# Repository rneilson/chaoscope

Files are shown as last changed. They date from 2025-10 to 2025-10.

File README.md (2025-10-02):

# Chaoscope

Infrared camera, Raspberry Pi, Lidar, in a convenient ~~vampire hunting~~ pistol grip form factor.

It's mostly ten-year-old kit -- a Pi 2, a 5 MP IR cut cam -- but hey, this
is more productive than the scrap heap...

### Major Components

- [Raspberry Pi 2 B](https://www.raspberrypi.com/products/raspberry-pi-2-model-b/)
- [Waveshare IR CUT 5MP camera](https://www.waveshare.com/wiki/RPi_IR-CUT_Camera)
- [M5Stack dual button unit](https://docs.m5stack.com/en/unit/dual_button)
- INA219 current/voltage monitor
- TP5100 battery charger
- 5V switching buck/boost voltage regulator
- 1 x 18650 lithium-ion battery

### Final form

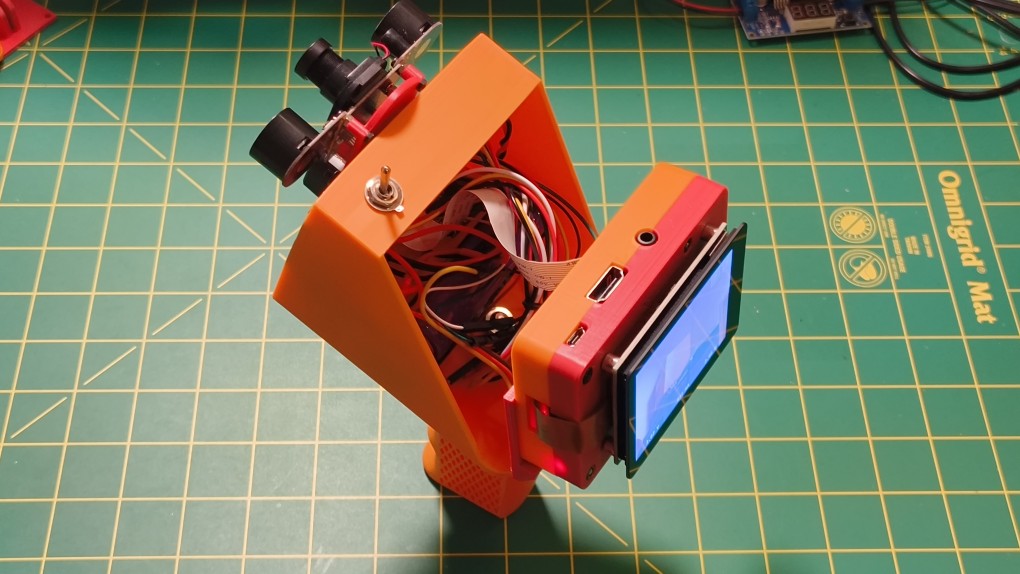
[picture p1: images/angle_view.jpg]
Angle view


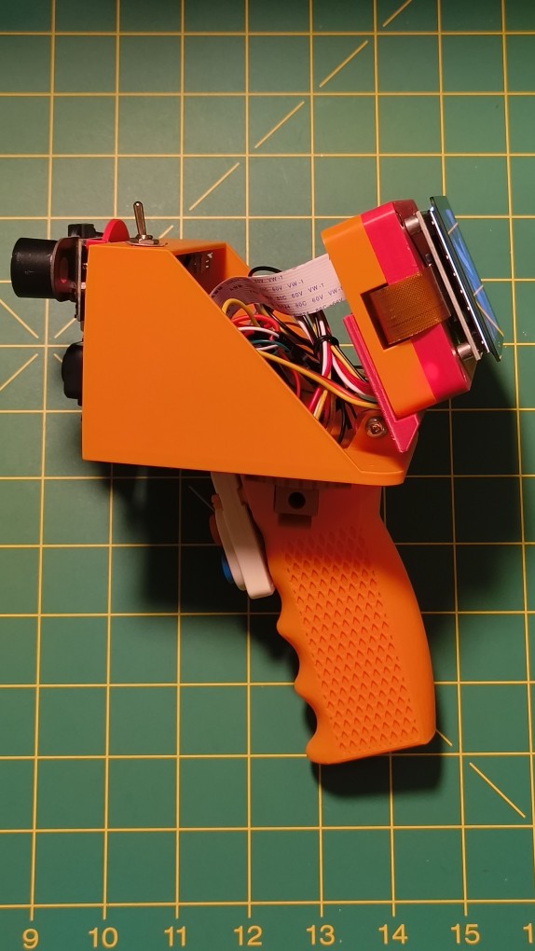
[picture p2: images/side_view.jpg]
Side view


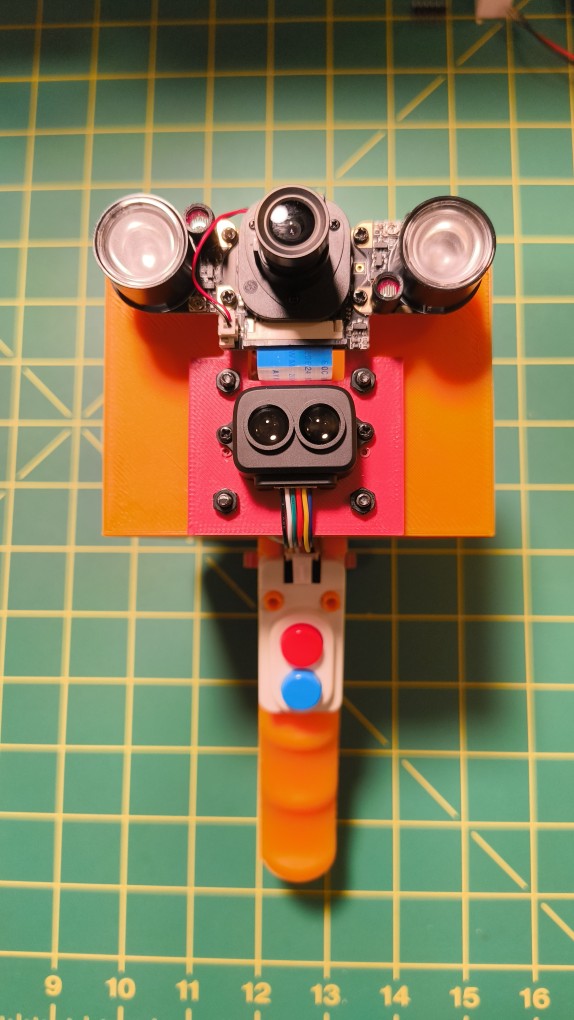
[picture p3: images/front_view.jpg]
Front view


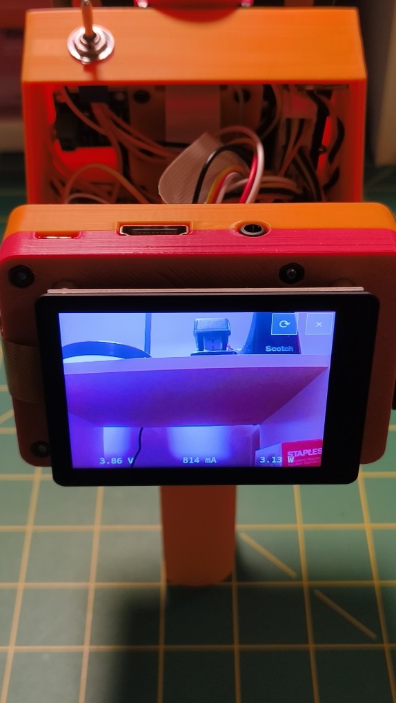
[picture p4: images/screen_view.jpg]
Screen view


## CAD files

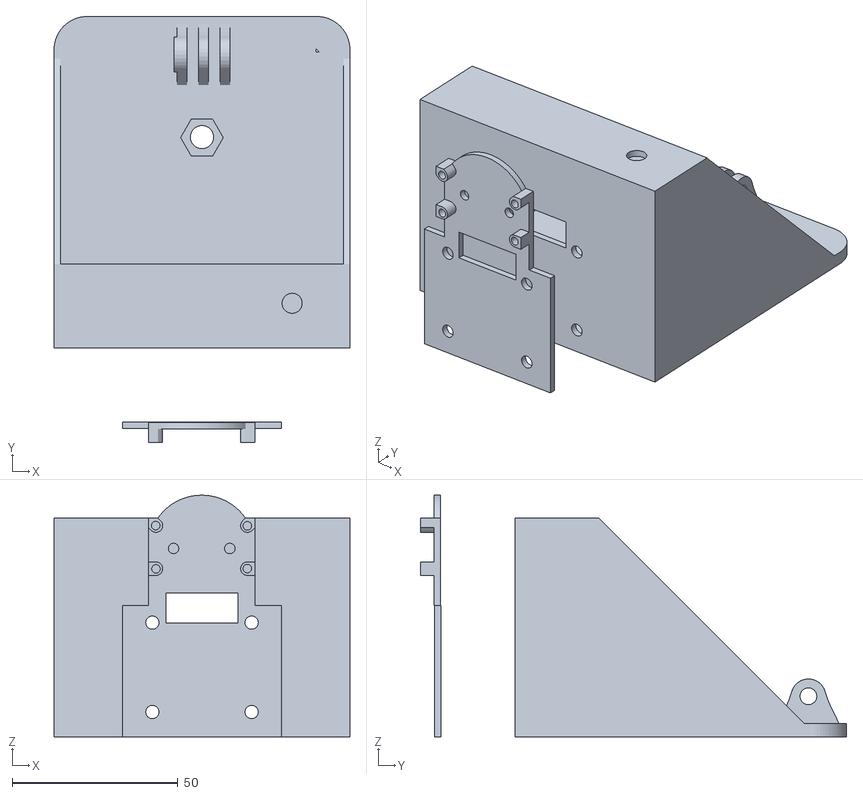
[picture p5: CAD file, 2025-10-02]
files/Camera bracket tall.stl
89.4 x 128.7 x 73.0

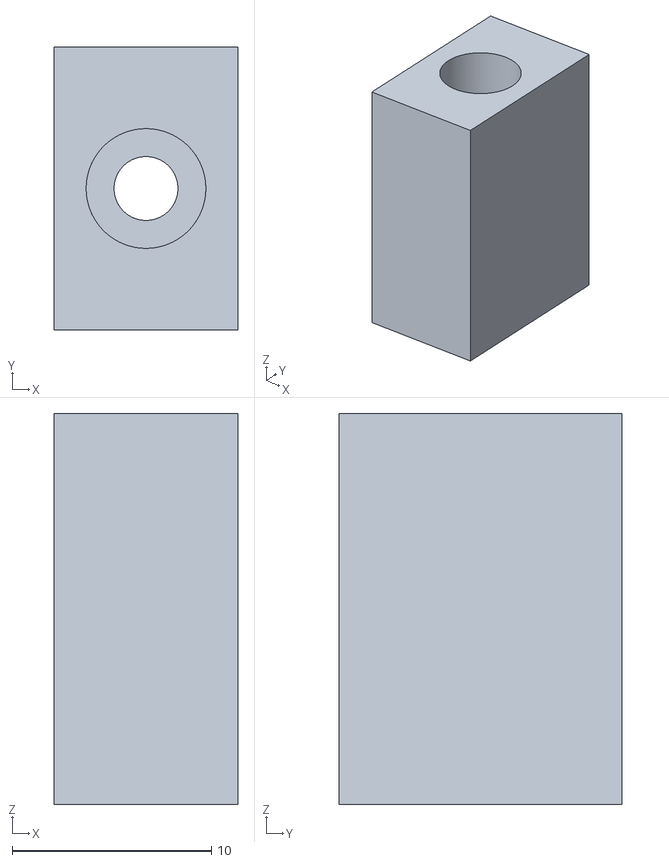
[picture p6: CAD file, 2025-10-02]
files/grip-insert.stl
9.20 x 14.2 x 19.6

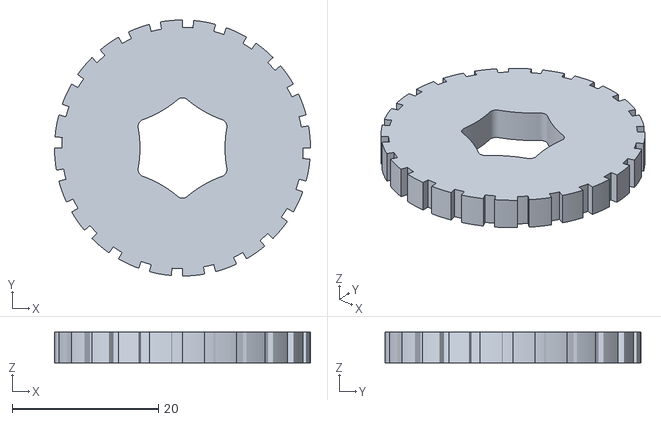
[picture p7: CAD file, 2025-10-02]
files/grip-thumbwheel.stl
35.0 x 35.0 x 4.20

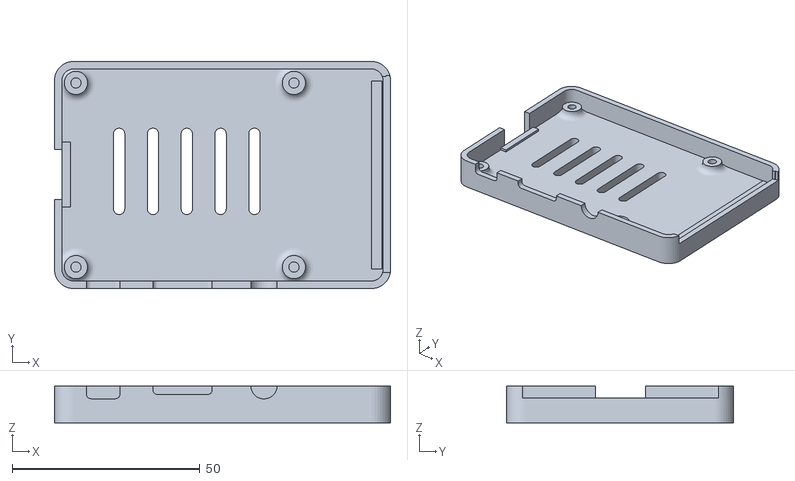
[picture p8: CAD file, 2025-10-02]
files/Pi3_Bottom_Vents.stl
89.4 x 60.4 x 9.75

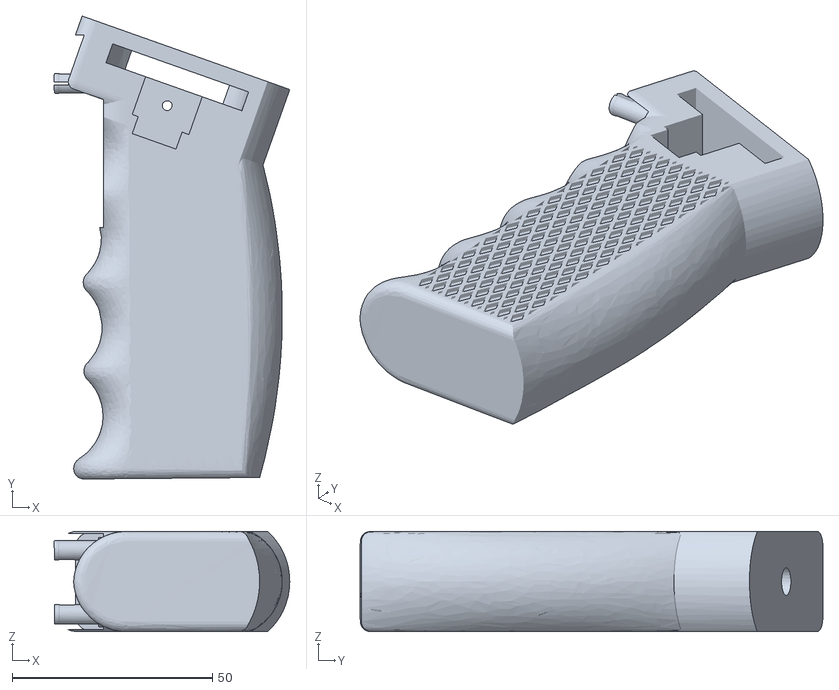
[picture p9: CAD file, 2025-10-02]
files/Pistol grip with dual button slot v2.stl
58.8 x 115.6 x 25.0

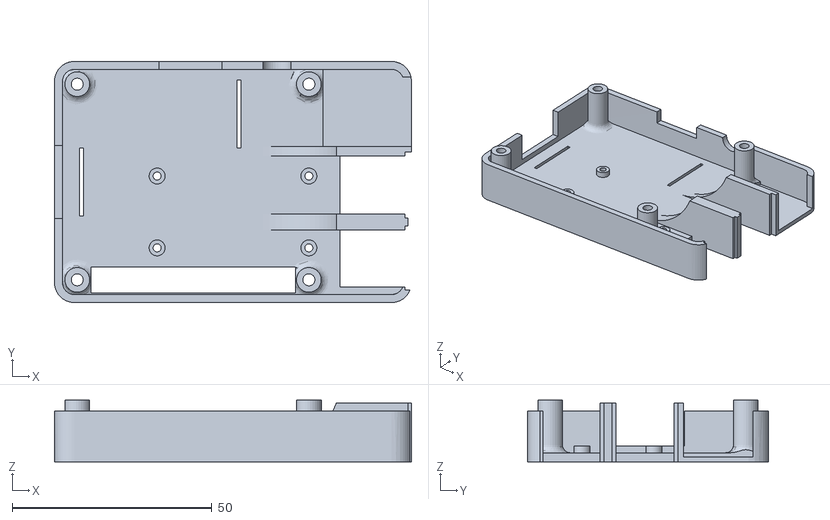
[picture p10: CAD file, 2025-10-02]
files/Pi3_Top_GPIO_modified_2.stl
89.4 x 60.4 x 15.5

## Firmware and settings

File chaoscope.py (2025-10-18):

import json
import os
import sys
from collections import deque
from dataclasses import dataclass
from datetime import datetime
from enum import StrEnum
from math import cos, radians, sin
from pathlib import Path
from time import sleep
from typing import TYPE_CHECKING, Any, Callable

import numpy as np
from PyQt5.QtCore import (
    Qt,
    QPoint,
    QObject,
    QRect,
    QThread,
    QTimer,
    pyqtSignal,
    pyqtSlot,
)
from PyQt5.QtGui import QFont, QPainter, QPaintEvent, QPen
from PyQt5.QtWidgets import (
    QPushButton,
    QHBoxLayout,
    QVBoxLayout,
    QApplication,
    QWidget,
    QLabel,
)
from ahrs import DEG2RAD, RAD2DEG
from ahrs.common.quaternion import Quaternion
from ahrs.filters.tilt import Tilt
from ahrs.filters.madgwick import Madgwick
from gpiozero import Button, DigitalInputDevice
from numpy import array, ndarray
from smbus2 import SMBus

from chaoscope_lib.inertial import IMU, ONE_G
from chaoscope_lib.magnometer import Magnometer, MagnometerCalibration

if TYPE_CHECKING:
    from picamera2 import CompletedRequest, Picamera2  # type: ignore
    from picamera2.encoders import H264Encoder  # type: ignore
    from picamera2.outputs import PyavOutput  # type: ignore
    from picamera2.previews.qt import QGlPicamera2  # type: ignore

TRANSLUCENT_STYLESHEET = (
    "color: white; background-color: rgba(255, 255, 255, 63); border: 1px solid white; "
)
TRANSPARENT_STYLESHEET = (
    "color: white; background-color: rgba(255, 255, 255, 0); border: none; "
)
FONT_SM = QFont("Deja Vu Sans Mono", 12)
FONT_MD = QFont("Deja Vu Sans Mono", 18)
FONT_LG = QFont("Deja Vu Sans Mono", 24)

LIDAR_I2C_ADDRESS = 0x10
LIDAR_REG_DIST = 0x00
LIDAR_REG_ENABLE = 0x25
LIDAR_REG_FREQ = 0x26
LIDAR_REG_MODE = 0x23
LIDAR_REG_SAVE = 0x20
LIDAR_REG_REBOOT = 0x21
LIDAR_REG_TRIGGER = 0x24

ENABLE_RETICLE = True

BASE_DIR = Path(__file__).parent
PHOTO_DIR = BASE_DIR / "photos"
CAL_FILE = BASE_DIR / "calibration.json"

if run_dir := os.environ.get("XDG_RUNTIME_DIR"):
    SHUTDOWN_FILE = Path(run_dir) / "chaoscope-shutdown"
else:
    SHUTDOWN_FILE = None

CURRENT_TZ = datetime.now().astimezone().tzinfo


class OverlayWindow(QWidget):
    exit_code: int
    finish = pyqtSignal()

    def __init__(
        self,
        parent: QWidget | None = None,
        flags: Qt.WindowFlags | Qt.WindowType = Qt.WindowFlags(),
    ) -> None:
        super().__init__(parent, flags)
        self.setWindowFlag(Qt.WindowType.FramelessWindowHint)
        self.setWindowTitle("Chaoscope controls")
        self.setAttribute(Qt.WidgetAttribute.WA_TranslucentBackground, on=True)
        self.setCursor(Qt.CursorShape.BlankCursor)
        self.setFont(FONT_MD)
        self.exit_code = 0

    def bring_to_front(self):
        self.show()
        self.raise_()
        self.activateWindow()

    def on_close(self):
        # Set special exit code to indicate shutdown after exit
        self.exit_code = 2
        self.finish.emit()

    def on_restart(self):
        # Set successful exit code
        self.exit_code = 0
        self.finish.emit()


class Clock(QWidget):
    def __init__(
        self,
        parent: QWidget | None = None,
        flags: Qt.WindowFlags | Qt.WindowType = Qt.WindowFlags(),
    ):
        super().__init__(parent=parent, flags=flags)
        self._layout = QVBoxLayout(self)
        self._clock = QLabel()
        self._timer = QTimer(self)
        self._timer.setInterval(100)
        self._timer.timeout.connect(self.update_ui)
        self._timer.start()
        self.init_ui()

    def init_ui(self):
        self._clock.setStyleSheet(TRANSPARENT_STYLESHEET)
        self._clock.setFont(FONT_MD)
        self._clock.setAlignment(Qt.AlignmentFlag.AlignCenter)
        self._layout.addWidget(self._clock)
        self.update_ui()

    @pyqtSlot()
    def update_ui(self):
        now = datetime.now(tz=CURRENT_TZ)
        self._clock.setText(now.strftime("%Y-%m-%d %I:%M:%S %p"))
        self._clock.adjustSize()
        self.adjustSize()


@dataclass
class PowerState:
    voltage: float | None
    current: float | None
    power: float | None


class PowerReader(QObject):
    INTERVAL_MS = 1000

    _hwmon_dir: Path | None
    _timer: QTimer | None
    output = pyqtSignal(PowerState)
    finished = pyqtSignal()

    def __init__(self, parent: QObject | None = None):
        super().__init__(parent=parent)
        self._hwmon_dir = self._find_hwmon_dir()
        self._timer = None

    def _find_hwmon_dir(self) -> Path | None:
        for subdir in Path("/sys/class/hwmon").glob("hwmon*"):
            name_file = subdir / "name"
            if name_file.exists() and name_file.read_text().strip() == "ina219":
                return subdir
        return None

    def start(self):
        self._timer = QTimer(self)
        self._timer.timeout.connect(self.check_power_state)
        self._timer.start(self.INTERVAL_MS)

    def stop(self):
        self._timer.stop()
        self._timer = None
        self.finished.emit()

    def check_power_state(self):
        voltage = self.get_voltage()
        current = self.get_current()
        power = self.get_power()
        self.output.emit(PowerState(voltage=voltage, current=current, power=power))

    def get_voltage(self) -> float | None:
        """
        Gets battery voltage in V from hwmon sysfs interface
        """
        voltage_file0 = self._hwmon_dir / "in0_input"
        voltage_file1 = self._hwmon_dir / "in1_input"
        try:
            voltage_str0 = voltage_file0.read_text()
            voltage_str1 = voltage_file1.read_text()
        except FileNotFoundError:
            return None

        voltage = (float(voltage_str0) + float(voltage_str1)) / 1_000

        return voltage

    def get_current(self) -> int | None:
        """
        Gets battery current in mA from hwmon sysfs interface
        """
        current_file = self._hwmon_dir / "curr1_input"
        try:
            current_str = current_file.read_text()
        except FileNotFoundError:
            return None

        current = int(current_str)

        return current

    def get_power(self) -> float | None:
        """
        Gets battery power in W from hwmon sysfs interface
        """
        power_file = self._hwmon_dir / "power1_input"
        try:
            power_str = power_file.read_text()
        except FileNotFoundError:
            return None

        power = float(power_str) / 1_000_000

        return power


class PowerLabelKind(StrEnum):
    VOLTAGE = "voltage"
    CURRENT = "current"
    POWER = "power"


class PowerLabel(QLabel):
    label_kind: PowerLabelKind
    power_state: PowerState

    def __init__(
        self,
        kind: PowerLabelKind,
        parent: QWidget | None = None,
        flags: Qt.WindowFlags | Qt.WindowType = Qt.WindowFlags(),
    ):
        super().__init__(parent=parent, flags=flags)
        self.label_kind = kind
        self.power_state = PowerState(None, None, None)
        self.init_ui()

    def init_ui(self):
        self.setStyleSheet(TRANSPARENT_STYLESHEET)
        self.setFont(FONT_MD)
        self.setAlignment(Qt.AlignmentFlag.AlignCenter)
        self.update_ui()

    def update_ui(self):
        match self.label_kind:
            case PowerLabelKind.VOLTAGE:
                v = self.power_state.voltage or 0.0
                self.setText(f"{v:.2f} V")
            case PowerLabelKind.CURRENT:
                i = int(self.power_state.current or 0.0)
                self.setText(f"{i:4} mA")
            case PowerLabelKind.POWER:
                p = self.power_state.power or 0.0
                self.setText(f"{p:.2f} W")

    @pyqtSlot(PowerState)
    def on_power_reading(self, power_state: PowerState):
        self.power_state = power_state
        self.update_ui()


class PowerMonitor(QWidget):
    power_reading = pyqtSignal(PowerState)

    def __init__(
        self,
        parent: QWidget | None = None,
        flags: Qt.WindowFlags | Qt.WindowType = Qt.WindowFlags(),
    ) -> None:
        super().__init__(parent, flags)

        self.voltage_label = PowerLabel(PowerLabelKind.VOLTAGE)
        self.current_label = PowerLabel(PowerLabelKind.CURRENT)
        self.power_label = PowerLabel(PowerLabelKind.POWER)

        self.power_monitor_layout = QHBoxLayout(self)
        self.power_monitor_layout.addWidget(self.voltage_label)
        self.power_monitor_layout.addWidget(self.current_label)
        self.power_monitor_layout.addWidget(self.power_label)

        self.power_reading.connect(self.voltage_label.on_power_reading)
        self.power_reading.connect(self.current_label.on_power_reading)
        self.power_reading.connect(self.power_label.on_power_reading)


@dataclass
class HeadingState:
    roll: float
    pitch: float
    yaw: float

    def apply_declination(self, dec: float) -> None:
        """
        Apply magnetic declination to observed yaw value.
        """
        self.yaw += dec
        if self.yaw > 180.0:
            self.yaw -= 360.0
        elif self.yaw < -180.0:
            self.yaw += 360.0


class HeadingReader(QObject):
    READING_INTERVAL_MS = 40  # 25 Hz for now
    FINAL_ROTATION = Quaternion(rpy=array([0.0, 0.0, 90.0]) * DEG2RAD)
    MAG_DECLINATION = -16.2  # degrees

    heading = pyqtSignal(HeadingState)
    finished = pyqtSignal()
    _i2c: SMBus | None
    _imu: IMU | None
    _mag: Magnometer | None
    _timer: QTimer | None
    _gyro_offsets: tuple[float, float, float] | None
    _mag_calibration: MagnometerCalibration | None
    _filter: Madgwick | None
    _headings: deque[Quaternion]
    _last_heading: Quaternion
    _last_reading: datetime

    def __init__(
        self,
        parent: QObject | None = None,
        gyro_offsets: tuple[float, float, float] = (0.0, 0.0, 0.0),
        mag_calibration: MagnometerCalibration | None = None,
    ):
        super().__init__(parent=parent)
        self._timer = None
        self._i2c = None
        self._imu = None
        self._mag = None
        self._gyro_offsets = gyro_offsets
        self._mag_calibration = mag_calibration
        self._filter = None
        self._headings = deque(maxlen=int(500 / self.READING_INTERVAL_MS))
        self._last_heading = Quaternion()
        self._last_reading = datetime.now(tz=CURRENT_TZ)

    def start(self):
        try:
            assert self._gyro_offsets
            assert self._mag_calibration
            # Open I2C bus
            self._i2c = SMBus(1)
            # Setup IMU and magnometer
            self._imu = IMU(self._i2c, self._gyro_offsets)
            if self._mag_calibration:
                self._mag = Magnometer(
                    self._i2c,
                    hard_offsets=self._mag_calibration.hard_offsets,
                    soft_offsets=self._mag_calibration.soft_offsets,
                    mag_field=self._mag_calibration.mag_field,
                )
            else:
                self._mag = Magnometer(self._i2c)
            # Setup AHRS filter
            _gyr, acc, mag = self.take_reading()
            self._last_reading = datetime.now(tz=CURRENT_TZ)
            self._last_heading = self.get_heading(acc=acc, mag=mag)
            self._headings.append(self._last_heading)
            # Setup timer
            self._timer = QTimer(self)
            self._timer.timeout.connect(self.update_heading)
            self._timer.start(self.READING_INTERVAL_MS)
        except Exception as e:
            print(f"Error starting heading reader: {e}", file=sys.stderr)
            raise

    def stop(self):
        self._timer.stop()
        self._timer = None
        self.finished.emit()

    def take_reading(self) -> tuple[ndarray, ndarray, ndarray]:
        gyr = array([radians(v) for v in self._imu.get_scaled_gyro()])  # rad/s
        acc = array([v * ONE_G for v in self._imu.get_scaled_accel()])  # m/s^2
        mag = array(self._mag.get_scaled_mag())  # uT
        return (gyr, acc, mag)

    def get_heading(self, acc: ndarray, mag: ndarray) -> Quaternion:
        # For whatever reason, negating the accelerometer reading properly aligns
        # the resulting roll/pitch
        heading = Quaternion(
            Tilt().estimate(acc=acc * -1, mag=mag, representation="quaternion")
        )
        # Rotate new heading +90 deg around z-axis as per installation orientation
        heading_rot = Quaternion(heading * self.FINAL_ROTATION)

        return heading_rot

    def avg_headings(self) -> Quaternion:
        accum = np.array([0.0, 0.0, 0.0, 0.0])
        # TODO: setup weights to favor most recent

        for q in self._headings:
            if np.dot(accum, q) < 0.0:
                accum -= q
            else:
                accum += q

        return Quaternion(accum)

    @pyqtSlot()
    def update_heading(self):
        _gyr, acc, mag = self.take_reading()
        new_reading = datetime.now(tz=CURRENT_TZ)
        # TODO: we should weight by dt maybe?
        _dt = (new_reading - self._last_reading).total_seconds()
        self._last_reading = new_reading

        self._last_heading = self.get_heading(acc=acc, mag=mag)
        self._headings.append(self._last_heading)
        cur_heading = self.avg_headings()

        roll, pitch, yaw = (float(v) for v in (cur_heading.to_angles() * RAD2DEG))
        heading = HeadingState(roll=roll, pitch=pitch, yaw=yaw)
        heading.apply_declination(self.MAG_DECLINATION)
        self.heading.emit(heading)


class HeadingLabelKind(StrEnum):
    ROLL = "roll"
    PITCH = "pitch"
    YAW = "yaw"


class HeadingLabel(QLabel):
    label_kind: HeadingLabelKind
    heading_state: HeadingState

    def __init__(
        self,
        kind: HeadingLabelKind,
        parent: QWidget | None = None,
        flags: Qt.WindowFlags | Qt.WindowType = Qt.WindowFlags(),
    ):
        super().__init__(parent=parent, flags=flags)
        self.label_kind = kind
        self.heading_state = HeadingState(0.0, 0.0, 0.0)
        self.init_ui()

    def init_ui(self):
        self.setStyleSheet(TRANSPARENT_STYLESHEET)
        self.setFont(FONT_MD)
        self.setAlignment(Qt.AlignmentFlag.AlignCenter)
        self.update_ui()

    def update_ui(self):
        match self.label_kind:
            case HeadingLabelKind.ROLL:
                r = int(round(self.heading_state.roll))
                self.setText(f"ϕ {r}°")
            case HeadingLabelKind.PITCH:
                p = int(round(self.heading_state.pitch))
                self.setText(f"θ {p}°")
            case HeadingLabelKind.YAW:
                y = int(round(self.heading_state.yaw))
                self.setText(f"Ψ {y}°")

    @pyqtSlot(HeadingState)
    def on_heading_update(self, heading_state: HeadingState):
        self.heading_state = heading_state
        self.update_ui()


class HeadingIndicator(QWidget):
    on_heading_update = pyqtSignal(HeadingState)

    def __init__(
        self,
        parent: QWidget | None = None,
        flags: Qt.WindowFlags | Qt.WindowType = Qt.WindowFlags(),
    ) -> None:
        super().__init__(parent, flags)

        self.roll_label = HeadingLabel(HeadingLabelKind.ROLL)
        self.pitch_label = HeadingLabel(HeadingLabelKind.PITCH)
        self.yaw_label = HeadingLabel(HeadingLabelKind.YAW)

        self.heading_monitor_layout = QHBoxLayout(self)
        self.heading_monitor_layout.addWidget(self.roll_label)
        self.heading_monitor_layout.addWidget(self.pitch_label)
        self.heading_monitor_layout.addWidget(self.yaw_label)

        self.on_heading_update.connect(self.roll_label.on_heading_update)
        self.on_heading_update.connect(self.pitch_label.on_heading_update)
        self.on_heading_update.connect(self.yaw_label.on_heading_update)


class ButtonObject(QObject):
    button: Button
    button_active: bool
    button_pressed = pyqtSignal()
    button_held = pyqtSignal()
    button_released = pyqtSignal()

    def __init__(
        self,
        pin: int,
        hold_time: float | None = None,
        parent: QWidget | None = None,
    ):
        super().__init__(parent=parent)
        button_args = {"bounce_time": 0.01}
        if hold_time is not None:
            button_args["hold_time"] = hold_time
            # button_args["hold_repeat"] = True
        self.button = Button(pin, **button_args)
        self.button_active = False
        self.button.when_activated = self.on_button_pressed
        self.button.when_deactivated = self.on_button_released
        if hold_time is not None:
            self.button.when_held = self.on_button_held

    def on_button_held(self):
        self.button_held.emit()

    def on_button_pressed(self):
        self.button_active = True
        self.button_pressed.emit()

    def on_button_released(self):
        self.button_active = False
        self.button_released.emit()
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

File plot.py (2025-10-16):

from pathlib import Path
from typing import Generator

import numpy as np
from matplotlib import pyplot as plt
from matplotlib.figure import Figure

BASE_DIR = Path(__file__).parent.resolve()
RAW_MAG_FILE = BASE_DIR / "raw_mag.txt"
CAL_MAG_FILE = BASE_DIR / "cal_mag.txt"
PLT_IMG_FILE_TMPL = "calibration-{}.png"


def plot_data(data: np.ndarray, title: str) -> Generator[Figure, None, None]:
    """
    Plot magnetometer data with 3D trajectory and projections.

    Adapted from:
    https://github.com/nliaudat/magnetometer_calibration/blob/main/calibrate.py
    """

    alpha = 1  # Transparency for scatter plots
    s = 2  # Size of scatter points

    # 3D trajectory
    fig_3d = plt.figure(figsize=(8, 5))
    ax1 = fig_3d.add_subplot(111, projection="3d")
    ax1.plot(data[:, 0], data[:, 1], data[:, 2])
    ax1.set_title(f"{title} Magnetometer Trajectory 3D")
    ax1.set_xlabel("X (µT)")
    ax1.set_ylabel("Y (µT)")
    ax1.set_zlabel("Z (µT)")
    ax1.set_aspect("equal")

    yield fig_3d

    # Calculate limits for consistent scaling
    min_val = np.min(data)
    max_val = np.max(data)

    # Projections figure
    fig_proj = plt.figure(figsize=(16, 4))

    # XY projection
    ax_xy = fig_proj.add_subplot(141)
    ax_xy.scatter(data[:, 0], data[:, 1], alpha=alpha, c="red", label="XY plane", s=s)
    ax_xy.set_title(f"{title} Magnetometer XY Projection")
    ax_xy.set_xlabel("X (µT)")
    ax_xy.set_ylabel("Y (µT)")
    ax_xy.set_xlim([min_val, max_val])
    ax_xy.set_ylim([min_val, max_val])
    ax_xy.set_aspect("equal")
    ax_xy.grid(True)
    ax_xy.legend()

    # XZ projection
    ax_xz = fig_proj.add_subplot(142)
    ax_xz.scatter(data[:, 0], data[:, 2], alpha=alpha, c="green", label="XZ plane", s=s)
    ax_xz.set_title(f"{title} Magnetometer XZ Projection")
    ax_xz.set_xlabel("X (µT)")
    ax_xz.set_ylabel("Z (µT)")
    ax_xz.set_xlim([min_val, max_val])
    ax_xz.set_ylim([min_val, max_val])
    ax_xz.set_aspect("equal")
    ax_xz.grid(True)
    ax_xz.legend()

    # YZ projection
    ax_yz = fig_proj.add_subplot(143)
    ax_yz.scatter(data[:, 1], data[:, 2], alpha=alpha, c="blue", label="YZ plane", s=s)
    ax_yz.set_title(f"{title} Magnetometer YZ Projection")
    ax_yz.set_xlabel("Y (µT)")
    ax_yz.set_ylabel("Z (µT)")
    ax_yz.set_xlim([min_val, max_val])
    ax_yz.set_ylim([min_val, max_val])
    ax_yz.set_aspect("equal")
    ax_yz.grid(True)
    ax_yz.legend()

    # Combined XYZ projection
    ax_xyz = fig_proj.add_subplot(144)
    ax_xyz.scatter(data[:, 0], data[:, 1], alpha=alpha, c="red", label="XY plane", s=s)
    ax_xyz.scatter(
        data[:, 0], data[:, 2], alpha=alpha, c="green", label="XZ plane", s=s
    )
    ax_xyz.scatter(data[:, 1], data[:, 2], alpha=alpha, c="blue", label="YZ plane", s=s)
    ax_xyz.set_title(f"{title} Magnetometer XYZ Combined")
    ax_xyz.set_xlabel("Coordinate (µT)")
    ax_xyz.set_ylabel("Coordinate (µT)")
    ax_xyz.set_xlim([min_val, max_val])
    ax_xyz.set_ylim([min_val, max_val])
    ax_xyz.set_aspect("equal")
    ax_xyz.grid(True)
    ax_xyz.legend()

    plt.tight_layout()

    yield fig_proj


def main():
    # TODO: make files configurable via args
    print("Loading data...")
    raw_data = np.loadtxt(RAW_MAG_FILE, delimiter=",")
    calibrated_data = np.loadtxt(CAL_MAG_FILE, delimiter=",")

    print("Plotting data...")

    i = 0

    def print_figure(fig: Figure):
        nonlocal i
        i += 1
        filename = BASE_DIR / PLT_IMG_FILE_TMPL.format(i)
        print(f"Saving {filename}...")
        fig.savefig(filename)

    for fig in plot_data(raw_data, "Raw"):
        print_figure(fig)

    for fig in plot_data(calibrated_data, "Calibrated"):
        print_figure(fig)


if __name__ == "__main__":
    main()

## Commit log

2025-09-16 Bare minimum working camera preview
2025-09-26 Initial QT5 app for camera preview with close button widget
2025-09-26 INA219 device tree overlay
2025-09-26 Tweak styles for labels and buttons
2025-09-26 Make ButtonLabel class for common functionality
2025-09-26 Add initial GPIO button hookup, only label changes to start
2025-09-26 Add power monitor in background thread with timer
2025-09-26 Put power monitor labels into a layout to space them out better
2025-09-27 Add reticle in center of frame, with placeholder button handling
2025-09-27 Some cleanup, move the widget containing the separate labels into a PowerMonitor class
2025-09-28 Set up RangeReader class for managing lidar, run in thread
2025-09-28 Pin framerate to 30fps
2025-09-28 Split close button into close and restart, with separate exit codes
2025-09-28 Create wrapper shell script to auto-restart and poweroff when done
2025-09-29 Move shutdown special exit code to 2; add barebones SIGINT handling
    Really the 'proper' solution for Qt and signals is more complicated,
    but since for now we're either restarting or shutting down, there
    shouldn't be *too* much to go wrong if it's not cleaned up...
    [chaoscope.py]
2025-09-29 Better match up reticle with actual lidar location and put label on top
2025-09-29 Use shutdown file instead of exit code for poweroff
    Run script from .profile which launches labwc, then checks
    $XDG_RUNTIME_DIR/chaoscope-shutdown for whether to poweroff
2025-09-30 Actually get the whole lidar thing working
    Also turn off the reticle by default because the dot parallax is too much
    [chaoscope.py]
2025-09-30 Change button text
2025-10-01 Replace button B with a (currently mocked out) capture button class
    [chaoscope.py]
2025-10-02 Fix some patch application fails
    [chaoscope.py]
2025-10-02 Switch resolutions around, use 2x2 binning for preview and stills, 720p for video
2025-10-02 Include STL files (and credits)
    [Camera bracket tall.stl, Pi3_Bottom_Vents.stl, Pi3_Top_GPIO_modified_2.stl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]
2025-10-03 Add video recording when holding down the capture button
2025-10-11 Rearrange things to start the GUI before the camera
2025-10-14 It's *calibration time bay bee!*
2025-10-14 We're getting readings! But they're wrong...
    [chaoscope.py]
2025-10-14 Some fixups, but things aren't fixed
    [calibrate.py, chaoscope.py]
2025-10-15 Good news: mostly got it working; bad news: the magnometer still isn't working great
    Had to negate the accelerometer reading to get the roll/pitch right (and at least
    the direction of yaw). Problem is, the magnometer doesn't seem to be giving solid
    enough readings to counteract gyro drift (which itself doesn't seem to be locked
    down enough even with the tweaked calibration)...
    [accel.py, calibrate.py, chaoscope.py]
2025-10-16 Big update, use new ellipsoid soft-iron calibration method
2025-10-17 Turns out averaging attitudes works better for our purposes than complex filters
    Really I'm just looking for relatively-instantaneous attitudes, ultimately so I can show
    a fancy artificial horizon line; since I'm not trying to integrate the data to track
    motion over time, the complex filters like Madgwick aren't really necessary. (And, to be
    honest, I was having trouble with python-ahrs' Madgwick initializing to the wrong
    attitude, and thus taking quite a while to converge on the real heading. This just skips
    the whole ordeal.) Will have to try out the FLAE (fast linear attitude estimator) soon,
    because the naive tilt one is quite slow; I had to go down to 25Hz to get decent perf.
    [chaoscope.py]
2025-10-18 Add magnetic declination correction for true north
    Still todo: get that info from somewhere instead of hardcoding
    [chaoscope.py]
